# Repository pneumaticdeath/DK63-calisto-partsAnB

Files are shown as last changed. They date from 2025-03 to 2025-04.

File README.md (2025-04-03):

# DK63 keyboard tray for Calisto 2 and a half 

This is an attempt to allow people to build new instances of the
[Calisto 2 and a Half](https://www.thingiverse.com/thing:6643913)
project on Thingiverse.  It's a wonderful project, but the 3 keyboards
used for the build are either no-longer avaiable, or are very expensive.

This project to adapt the DK63N keyboard tray to allow for the use 
of the DK63 in it's place, since it is still widely available (as
of March 2025).  This can probably be adapted to other keyboards as
well, though the basic design won't allow for keyboards much wider 
than the DK63 without fundamentally reworking the A & B parts.

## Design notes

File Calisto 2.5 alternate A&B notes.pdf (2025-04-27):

# Alternative Keyboard for Calisto 2 and a half

This deals with alternate A & B parts for the Calisto 2 and a half (https://www.thingiverse.com/thing:6643913) to accommodate the Dierya DK63 (https://www.amazon.com/DIERYA-T63-Mechanical-Bluetooth-Typist-Black/dp/B0CP5NTTKL) keyboard, which is still pretty widely available.

These parts started as the A & B parts for the DK63N that the original Calisto II (https://www.thingiverse.com/thing:4846997) used, but the DK63 is slightly wider and deeper than DK63N, and much taller, and also has a more complex profile.

A “plug” roughly matching the DK63 was made in OpenSCAD.

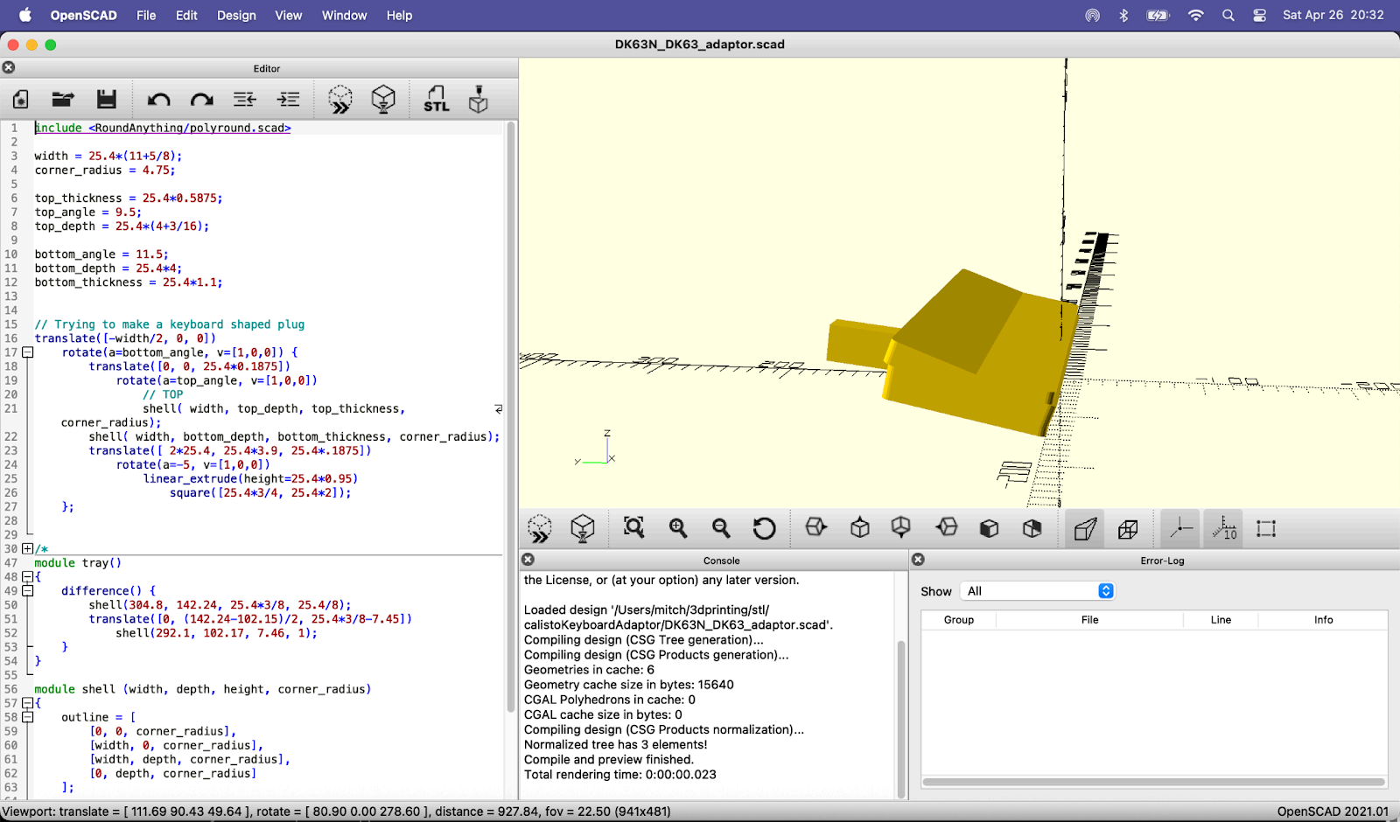
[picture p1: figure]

The original parts were then imported into Blender

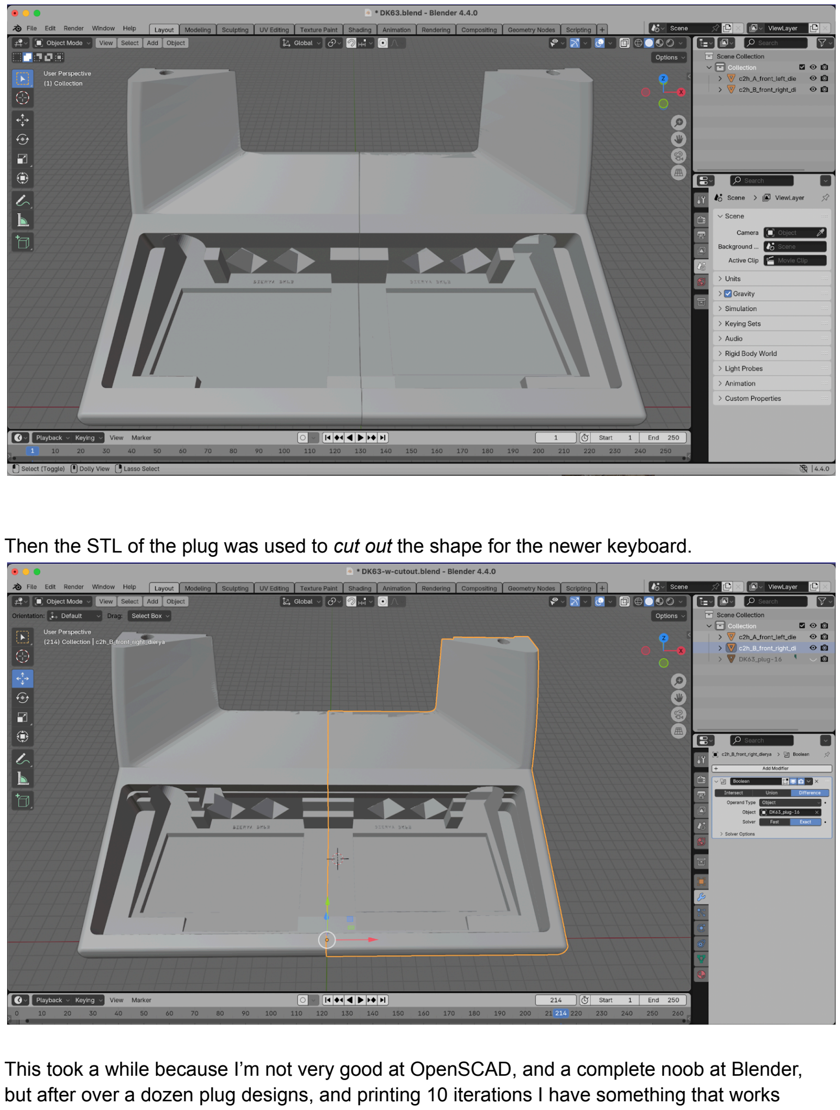
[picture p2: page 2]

Then the STL of the plug was used to cut out the shape for the newer keyboard.

This took a while because I’m not very good at OpenSCAD, and a complete noob at Blender, but after over a dozen plug designs, and printing 10 iterations I have something that works reasonably well. It’s not quite as polished as the original design, but the ugliness is hidden once assembled.

# Notes on printing and assembly

## Part A

### Supports

The cutout for the keyboard cable could probably use supports,but every time I’ve tried the result is awful, and the support material is difficult or impossible to remove. Without support the worst is that the roof looks a little messy when printed on my Prusa Mini. Your results may vary based on the printer. I did enable supports around the rounded parts of the base, and those came off fairly easily.

### Infill and layer height

Using 10% infill and 0.2mm layer height seemed fine on this part, and cut down on both printing time and material. With 2 or 3 walls and 4 or 5 top and bottom layers, it turned out pretty well. I used adaptive cubic infill, though I’m not sure it matters.

## Part B

### Supports

Supports on part B were pretty much the same as recommended in the original printing guide. I added supports around the rounded parts of the base, and that seemed sufficient.

Infill and layer height.

Here I found that 15-20% infill helped make the archway for the SD card reader a little sturdier. When I printed it at 10%, the archway broke off while I was trying to cut the supports for the retaining clip. I used super glue to repair it, but it seems very flimsy and delicate. My next iteration used 15%, and the archway did okay, though it still seemed delicate and eventually broke. Again I used adaptive cubic infill patterns.

0.2mm layer height gave pretty good results this time as well.

## Assembly

The top and front holes in the sides of both parts have relatively thin walls relative to the keyboard well. I’ve never had them fail, but if you use a more brittle filament (Silk, Matte, etc.), then it’s possible they might fail on peg insertion. Try to be gentle with those pegs especially.

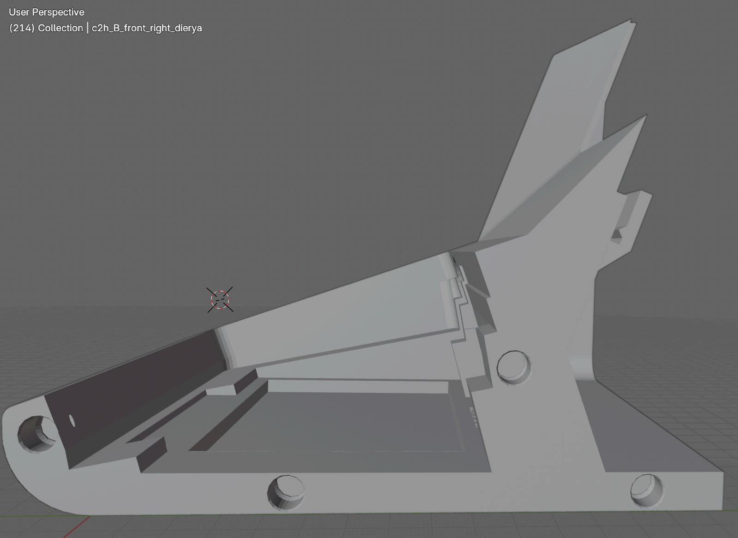
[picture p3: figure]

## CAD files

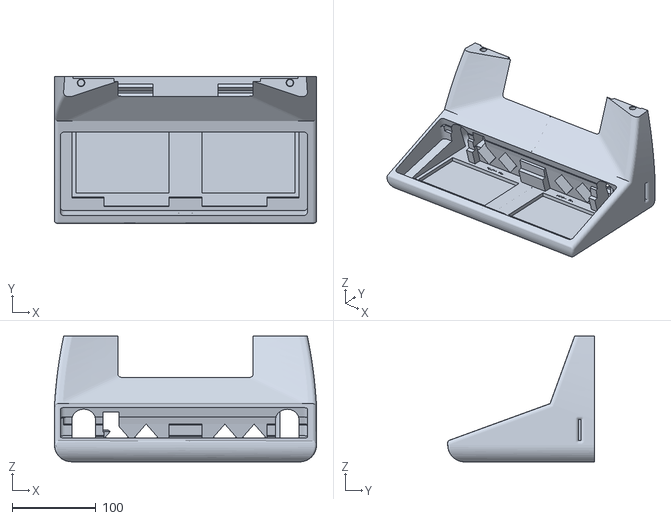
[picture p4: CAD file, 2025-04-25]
DK63-w-cutout.stl
312.9 x 175.0 x 150.1

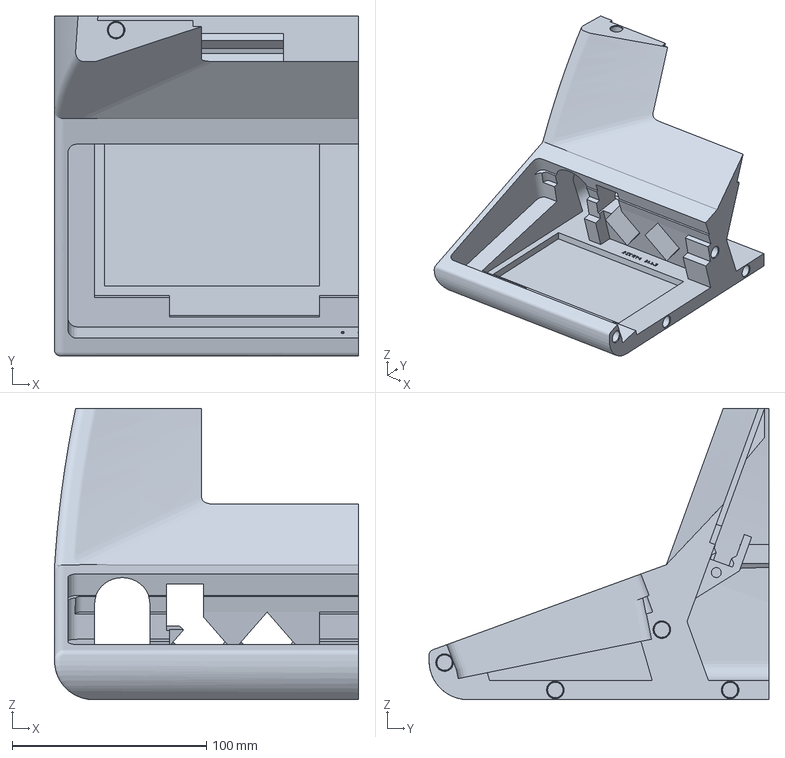
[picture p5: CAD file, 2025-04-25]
DK63-partA.3mf
156.5 x 175.0 x 150.0 mm

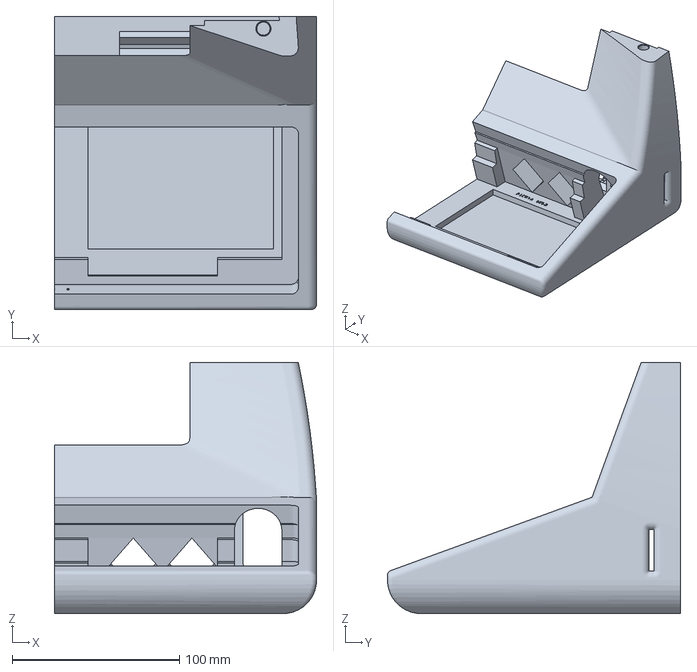
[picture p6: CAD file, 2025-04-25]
DK63-partB.3mf
156.5 x 175.0 x 150.0 mm

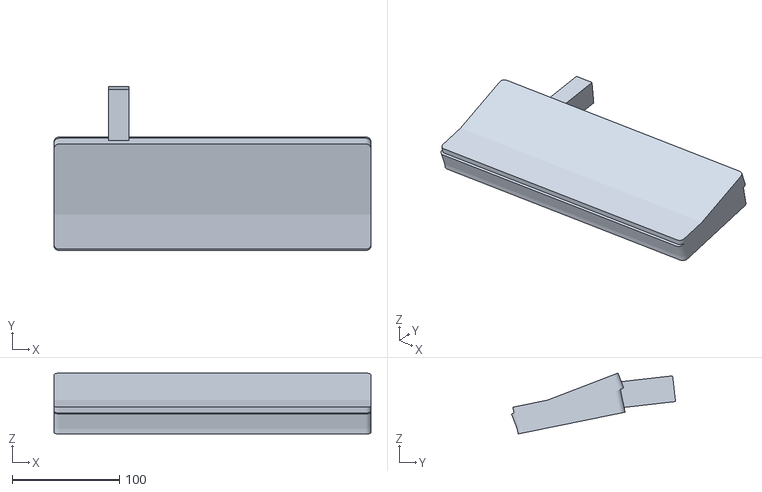
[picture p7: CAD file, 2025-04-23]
DK63_plug-15.stl
295.3 x 152.9 x 56.7

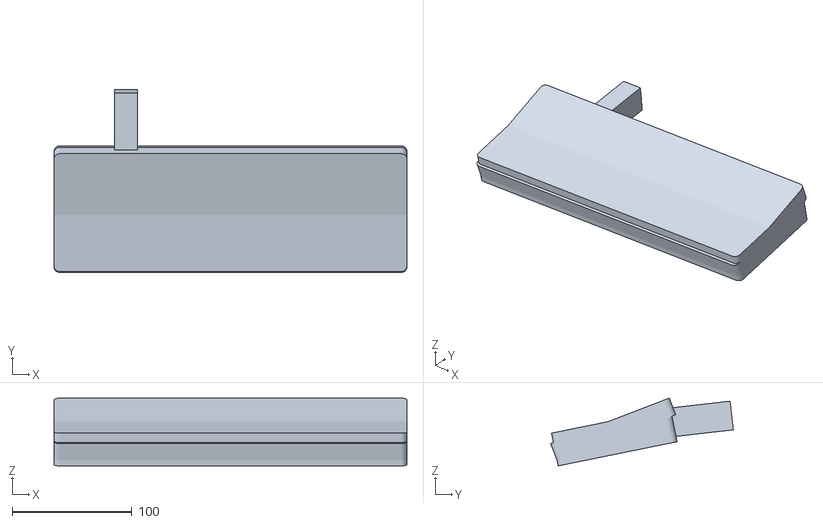
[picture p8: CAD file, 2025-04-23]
DK63_plug-16.stl
295.3 x 152.9 x 56.7

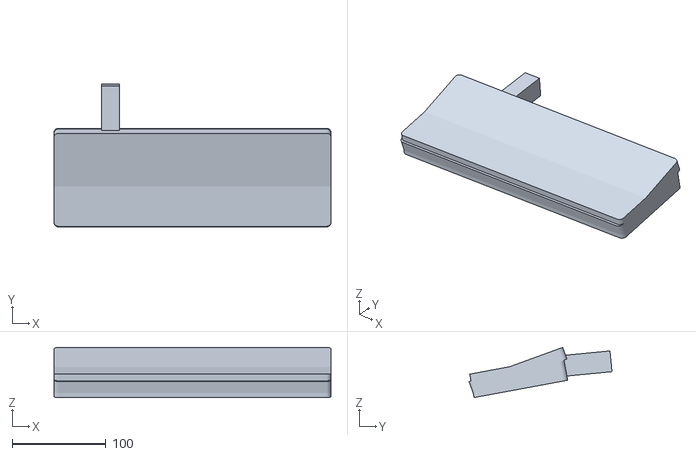
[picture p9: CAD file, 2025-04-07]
DK63_plug-14.stl
295.3 x 152.5 x 53.5

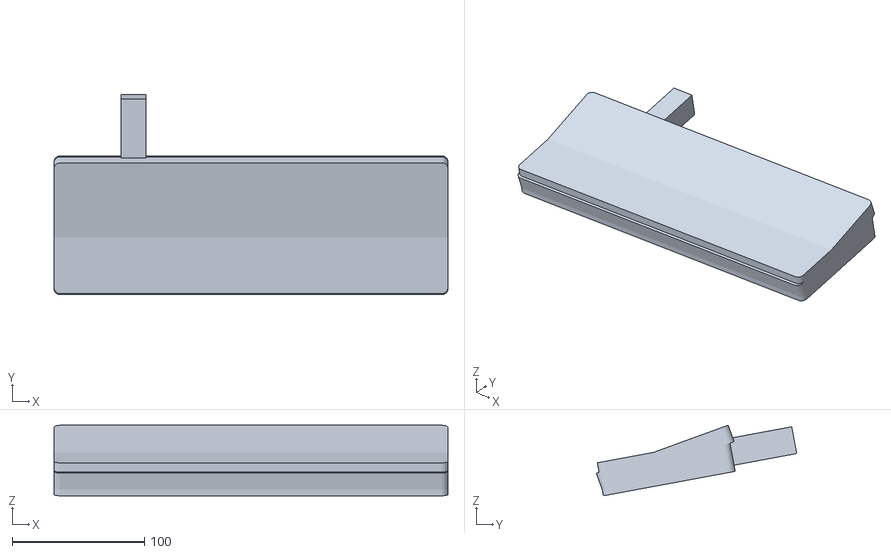
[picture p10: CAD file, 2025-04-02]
DK63_plug-12.stl
298.4 x 151.9 x 53.5

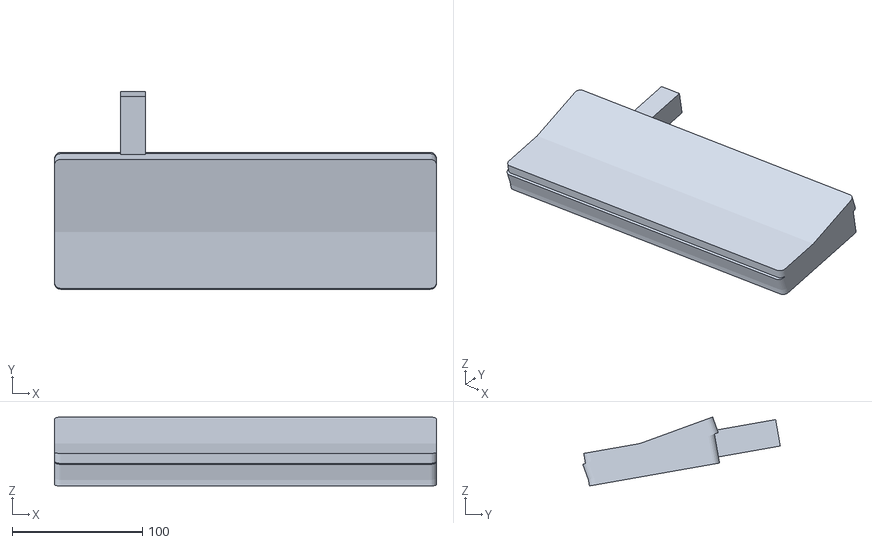
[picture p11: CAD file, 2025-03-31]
DK63_plug-10.stl
293.7 x 151.9 x 53.0

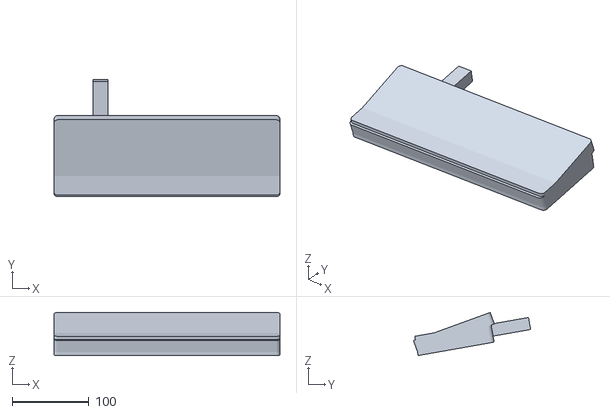
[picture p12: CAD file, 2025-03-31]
DK63_plug-8.stl
293.7 x 152.5 x 56.0

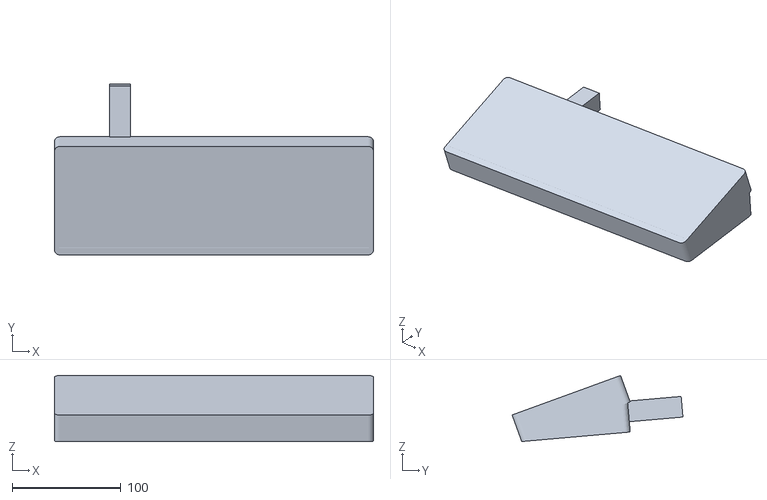
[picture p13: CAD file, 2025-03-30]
DK63_plug-7.stl
293.7 x 157.4 x 60.8

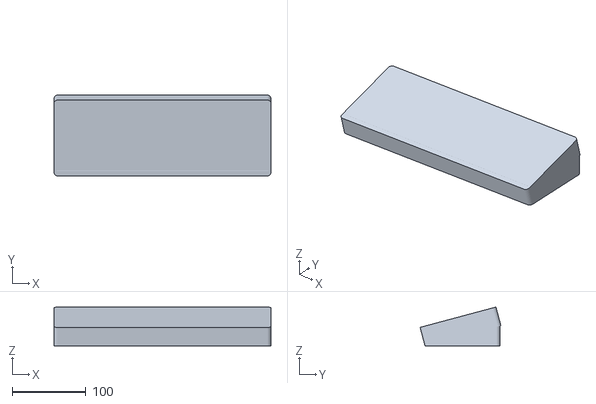
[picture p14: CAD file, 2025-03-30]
DK63_plug-3.stl
293.7 x 109.5 x 52.6

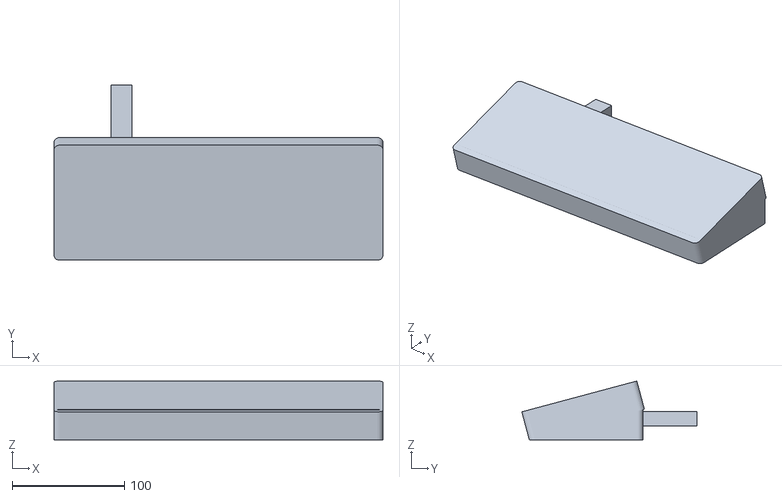
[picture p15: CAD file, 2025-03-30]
DK63_plug-4.stl
293.7 x 156.6 x 52.6

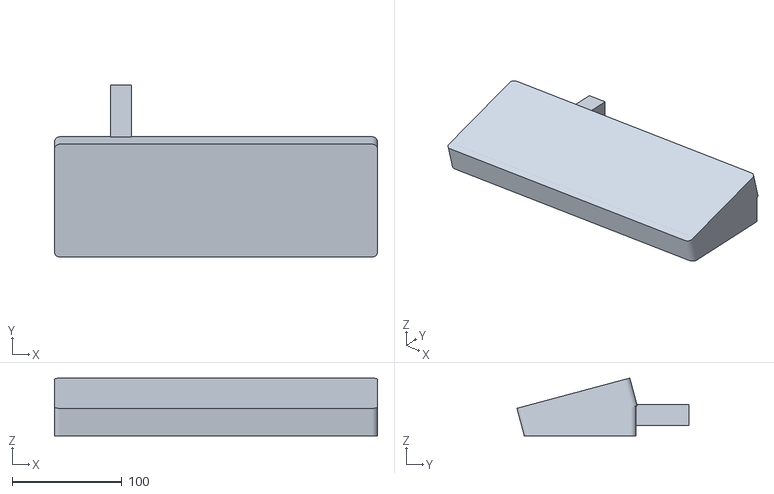
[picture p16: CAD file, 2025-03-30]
DK63_plug-5.stl
293.7 x 156.6 x 52.6

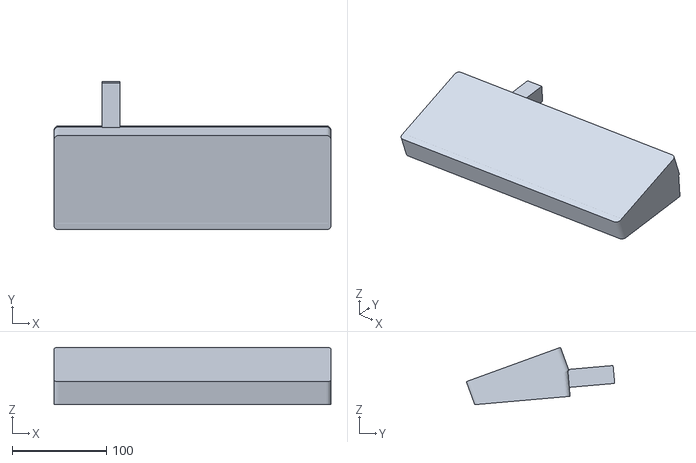
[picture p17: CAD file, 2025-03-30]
DK63_plug-6.stl
293.7 x 157.4 x 60.8

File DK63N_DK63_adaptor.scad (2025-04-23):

include <RoundAnything/polyround.scad>

width = 25.4*(11+5/8);
corner_radius = 4.75;

top_thickness = 25.4*0.5875;
top_angle = 9.5;
top_depth = 25.4*(4+3/16);

bottom_angle = 11.5;
bottom_depth = 25.4*4;
bottom_thickness = 25.4*1.1;


// Trying to make a keyboard shaped plug 
translate([-width/2, 0, 0])
    rotate(a=bottom_angle, v=[1,0,0]) {
        translate([0, 0, 25.4*0.1875])
            rotate(a=top_angle, v=[1,0,0])
                // TOP
                shell( width, top_depth, top_thickness, corner_radius);
        shell( width, bottom_depth, bottom_thickness, corner_radius);
        translate([ 2*25.4, 25.4*3.9, 25.4*.1875])
            rotate(a=-5, v=[1,0,0])
                linear_extrude(height=25.4*0.95)
                    square([25.4*3/4, 25.4*2]);
    };
                    

/* 
// Left = 1, right = -1
side = -1;

difference() {
    tray();
    translate([0,0,-10])
        linear_extrude(height=40)
            polygon([
                [ 0, -150],
                [ 0, 150],
                [ side*160, 150],
                [ side*160, -150]
            ]);
};
*/                    

module tray() 
{
    difference() {
        shell(304.8, 142.24, 25.4*3/8, 25.4/8);
        translate([0, (142.24-102.15)/2, 25.4*3/8-7.45]) 
            shell(292.1, 102.17, 7.46, 1);
    }
}

module shell (width, depth, height, corner_radius)
{
    outline = [
		[0, 0, corner_radius],
		[width, 0, corner_radius],
		[width, depth, corner_radius],
		[0, depth, corner_radius]
	];
	

		
	linear_extrude(height=height)
		polygon(polyRound(outline));
}

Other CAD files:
DK63_plug-11.stl
DK63_plug-13.stl
DK63_plug-9.stl
DK63_plug-2.stl
DK63-partA.stl
DK63-partB.stl
DK63-w-cutout.blend
DK63.blend
DK63_plug.stl

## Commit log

2025-03-30 Second attmept
    [DK63-partA.3mf, DK63-partA.stl, DK63-partB.3mf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]
2025-03-30 Third attempt
    [DK63-partA.3mf, DK63-partA.stl, DK63-partB.3mf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]
2025-03-31 Attempt #4 and #5
    [DK63-partA.3mf, DK63-partA.stl, DK63-partB.3mf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]
2025-03-31 Checking in the latest iteration for plug-10
    [DK63N_DK63_adaptor.scad]
2025-04-02 V7 of the parts
    [DK63-partA.3mf, DK63-partA.stl, DK63-partB.3mf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]
2025-04-03 Version 8... final version
    [DK63-partA.3mf, DK63-partA.stl, DK63-partB.3mf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]
2025-04-03 Final version of Blender file
    [DK63-w-cutout.blend]
2025-04-07 Version 9 -- untested
    [DK63-partA.3mf, DK63-partA.stl, DK63-partB.3mf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]
2025-04-21 Version 9.1 - keyboard better centered
    [DK63-partA.3mf, DK63-partA.stl, DK63-partB.3mf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]
2025-04-22 Version 9.1 3MF files
    [DK63-partA.3mf, DK63-partB.3mf]
2025-04-23 Version 10, slightly larger cable hole, slight tilt change, sligtly deeper
    [DK63-partA.3mf, DK63-partA.stl, DK63-partB.3mf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]
2025-04-25 Version 10.1.... same plug but better alignment/placement
    [DK63-partA.3mf, DK63-partA.stl, DK63-partB.3mf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]
